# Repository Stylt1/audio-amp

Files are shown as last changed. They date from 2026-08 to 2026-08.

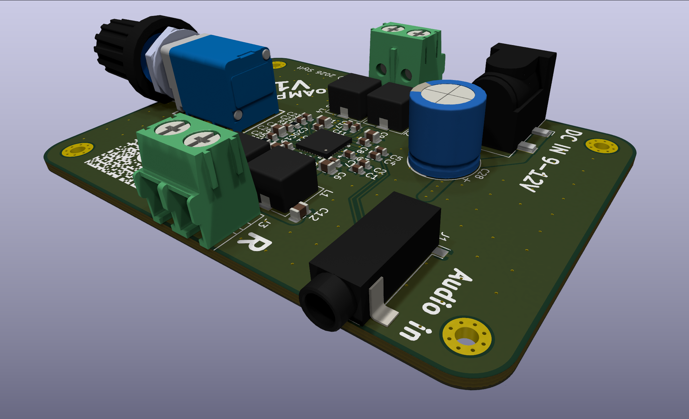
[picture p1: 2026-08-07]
img/Angle.backleft.png

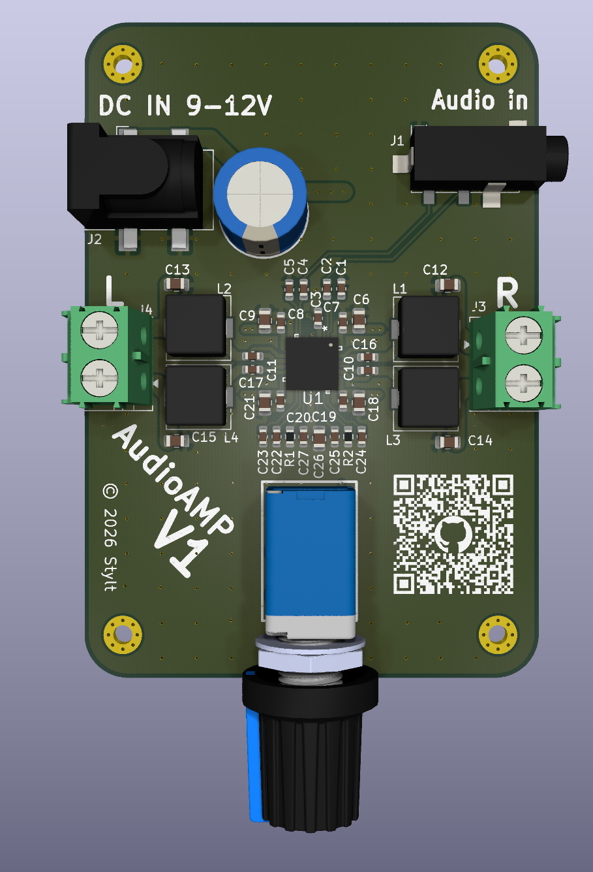
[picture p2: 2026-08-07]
img/Top.png

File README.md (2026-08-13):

View this project on [CADLAB.io](https://cadlab.io/project/30509). 

# 🎵 AudioAMP V1







This project features a 4-layer Class-D stereo audio amplifier based on **PAM8610** IC, delivering up to **2x 10W** output power.

---

## 📑 Table of Contents
- [✨ Key Features](#-key-features)
- [🛠️ Hardware Specifications](#️-hardware-specifications)
- [🧩 System Block Diagram](#-system-block-diagram)
- [📂 Repository Structure](#-repository-structure)
- [📸 Gallery & Schematics](#-gallery--schematics)

---

## ✨ Key Features

- **Amplification:** **PAM8610** (Class-D) stereo amplifier providing **2x 10W** output power.
- **4-Layer PCB Stackup:** 4-layer board design with dedicated power and ground planes:
  - **F.Cu (Top):** Signal + GND fill
  - **In1.Cu (Inner 1):** GND fill
  - **In2.Cu (Inner 2):** Power
  - **B.Cu (Bottom):** Secondary signal + GND fill
- **Supply Voltage Range:** from **9V to 12V DC** via standard DC05 DC Barrel Jack.
- **Volume & Power Control:** **10K logarithmic potentiometer** with an ON/OFF switch.
- **Connections:** 3.5 mm AUX stereo input jack and screw terminal blocks for Left (L) and Right (R) speakers.
- **Clean sound:** Bulk **2200 µF** electrolytic decoupling capacitor on power supply lines + LC output filters (33µH inductors) for ripple noise reduction and high signal fidelity.

---

## 🛠️ Hardware Specs

| Parameter | Specification |
| :--- | :--- |
| **Amplifier IC** | PAM8610 (Class-D Stereo) |
| **Output Power** | 10W + 10W RMS (into 8Ω @ 12V DC) |
| **Supply Voltage** | 9V – 12V DC |
| **PCB Stackup** | 4-Layer FR4 (Top, In1 [GND], In2 [PWR], Bottom) |
| **Power Connector** | 5.5 x 2.1 mm DC Barrel Jack |
| **Audio Input** | 3.5 mm Stereo AUX Jack |
| **Speaker Outputs** | Screw Terminal Blocks (Left & Right) |
| **Potentiometer** | 10K Logarithmic with ON/OFF Switch |
| **Filtration** | 2200 µF Bulk Electrolytic Cap + Output LC Filters |

---

## 🧩 System Block Diagram

<p align="center">
    BlockDiagram

</p>

---

## 📦 Production & Manufacturing Files

All production files required for manufacturing and PCBA assembly are located in the `production/` directory or under [GitHub Releases](../../releases):

---

## 📂 Repository Structure

```text
AudioAMP-V1/
├── hardware/              # KiCad project source files (.kicad_pro, .kicad_sch, .kicad_pcb)
├── img/                   # Documentation graphics, 3D renders, and layer views
├── production/            # Manufacturing deliverables
│   ├── bom/               # Bill of Materials (CSV)
│   ├── gerbers/           # 4-Layer Gerber files (ZIP archive)
│   └── schematics/        # Schematic diagram (PDF)
├── LICENSE.txt            # License
└── README.md              # Main project documentation
```

---

## 📸 Gallery & Schematics

### 3D Render
| Top View | Angled View |
|:---:|:---:|
| Top| Angle frontleft|

### 4-Layer PCB Layout

| Top Layer (F.Cu) | Inner Layer 1 (In1.Cu - GND) |
|:---:|:---:|
| F Cu| In1 Cu|

| Inner Layer 2 (In2.Cu - PWR) | Bottom Layer (B.Cu) |
|:---:|:---:|
| In2 Cu| B Cu|

### Schematic Diagram
Snímek obrazovky 2026-08-06 v 15 06 18

---

## 📝 License & Author

- **Designer:** Stylt
- **License:** ([CC BY-NC-ND 4.0 License](LICENSE))

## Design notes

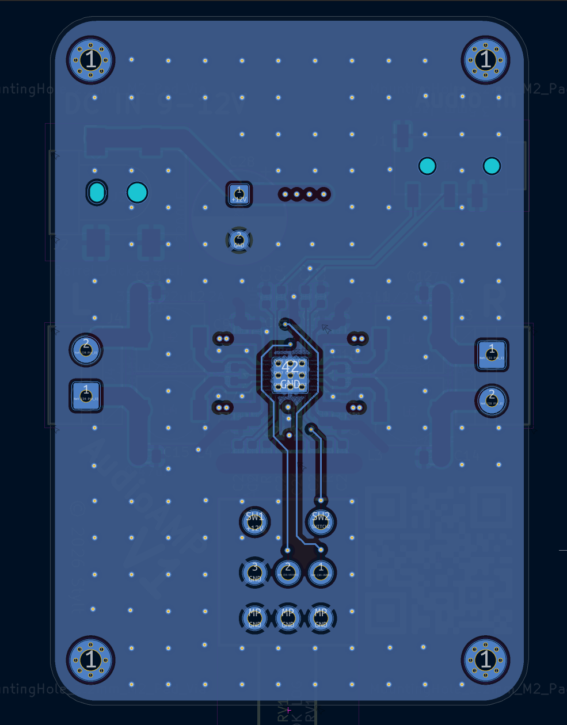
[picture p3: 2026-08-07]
img/B.Cu.png

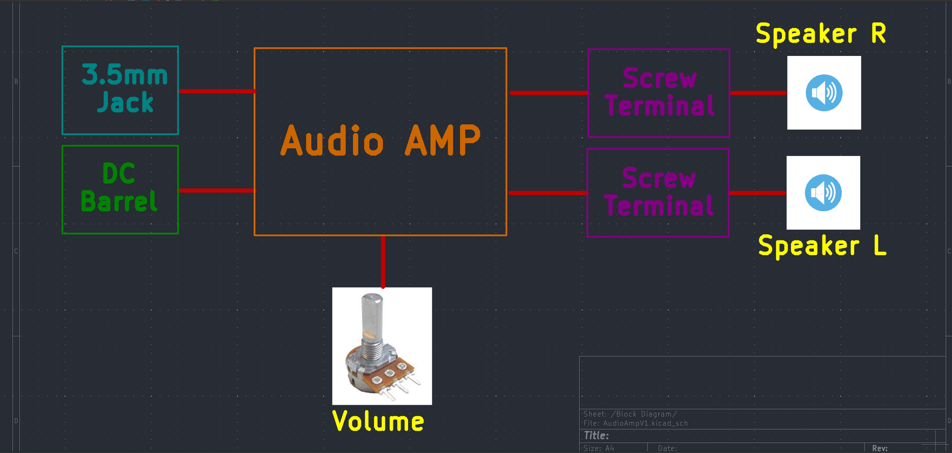
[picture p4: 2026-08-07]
img/BlockDiagram.png

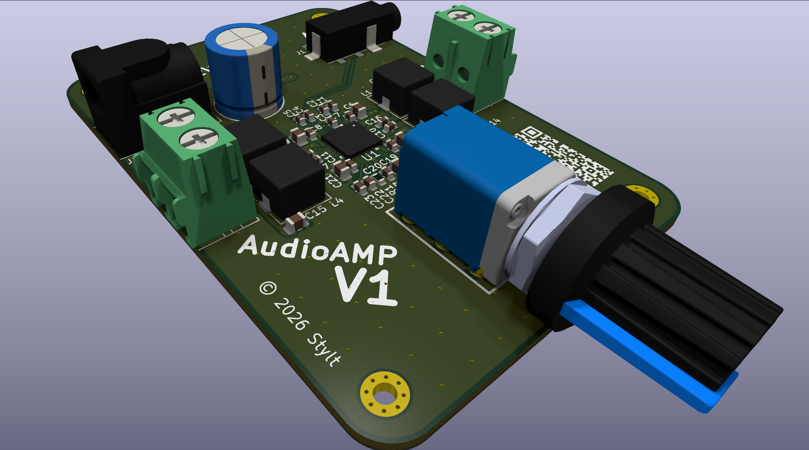
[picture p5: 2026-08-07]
img/Angle.frontleft.png

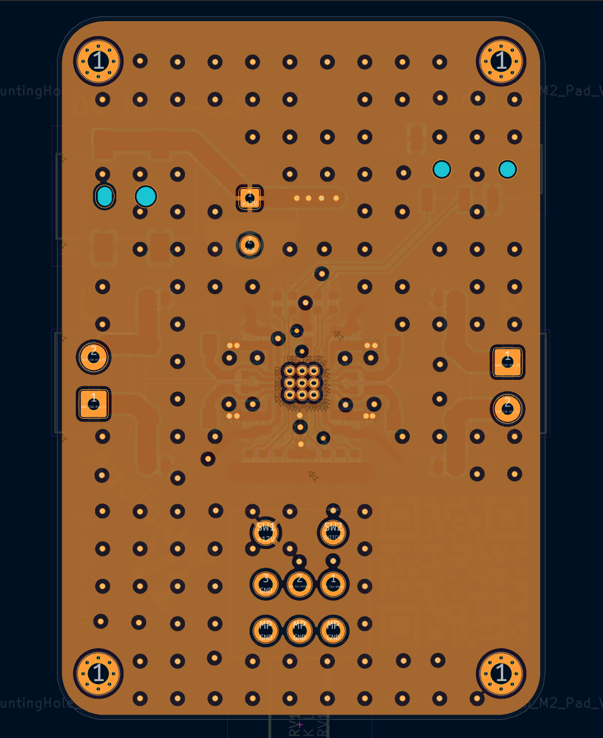
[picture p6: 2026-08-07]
img/In2.Cu.png

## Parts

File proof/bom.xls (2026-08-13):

Comment | Designator | Footprint | JLCPCB Part # | Qty | Ext.Price($)
100nF | C27 | 0603 | C14663 | 2 | 0.04
0,47uF | C12,C13,C14,C15 | 0805 | C16780 | 8 | 1.42
120K | R1 | 0603 | C25808 | 2 | 0.01
PAM8610 | U1 | QFN40-40P-POWER | C80797 | 2 | 2.74
1uF | C1,C10,C11,C16,C17,C19,C2,C20,C23,C24,C25,C3,C4,C5,C7,C8 | 0603 | C15849 | 32 | 2.42
220pF | C22 | 0603 | C1603 | 2 | 0.02
100K | R2 | 0603 | C25803 | 2 | 0.02
10uF | C18,C21,C26,C6,C9 | 0805 | C440198 | 10 | 3.22
2200uF | C28 | CP_Radial_D10.0mm_P5.00mm | C48970397 | 2 | 0.90
33uH/22uH,2A | L1,L2,L3,L4 | L_7.3x7.3_H4.5 | C207844 | 9 | 1.09
3,5mmJack | J1 | Jack_3.5mm_KoreanHropartsElec_PJ-320D-4A_Horizontal | C49563388 | 2 | 0.12
Barrel_Jack_Switch | J2 | BarrelJack_CLIFF_FC681465S_SMT_Horizontal | C52125089 | 2 | 0.64

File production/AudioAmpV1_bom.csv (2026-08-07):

Designator | Footprint | Quantity | Value | LCSC Part #
C1, C10, C11, C16, C17, C19, C2, C20, C23, C24, C25, C3, C4, C5, C7, C8 | 0603 | 16 | 1uF
C12, C13, C14, C15 | 0805 | 4 | 0,47uF
C18, C21, C26, C6, C9 | 0805 | 5 | 10uF
C22 | 0603 | 1 | 220pF
C27 | 0603 | 1 | 100nF
C28 | CP_Radial_D10.0mm_P5.00mm | 1 | 2200uF
J1 | Jack_3.5mm_KoreanHropartsElec_PJ-320D-4A_Horizontal | 1 | 3,5mm Jack
J2 | BarrelJack_CLIFF_FC681465S_SMT_Horizontal | 1 | Barrel_Jack_Switch
J3 | TerminalBlock_MaiXu_MX126-5.0-02P_1x02_P5.00mm | 1 | Speaker_R
J4 | TerminalBlock_MaiXu_MX126-5.0-02P_1x02_P5.00mm | 1 | Speaker_L
L1, L2, L3, L4 | L_7.3x7.3_H4.5 | 4 | 33uH/22uH, 2A
R1 | 0603 | 1 | 120K
R2 | 0603 | 1 | 100K
RV1 | AudioPot | 1 | 10K LOG
U1 | QFN40-40P-POWER | 1 | PAM8610

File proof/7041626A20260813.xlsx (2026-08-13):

?Designator | Value | Footprint | Quantity
J4 | Speaker_L | TerminalBlock_MaiXu_MX126-5.0-02P_1x02_P5.00mm | 1
J3 | Speaker_R | TerminalBlock_MaiXu_MX126-5.0-02P_1x02_P5.00mm | 1
RV1 | 10KLOG | AudioPot | 1

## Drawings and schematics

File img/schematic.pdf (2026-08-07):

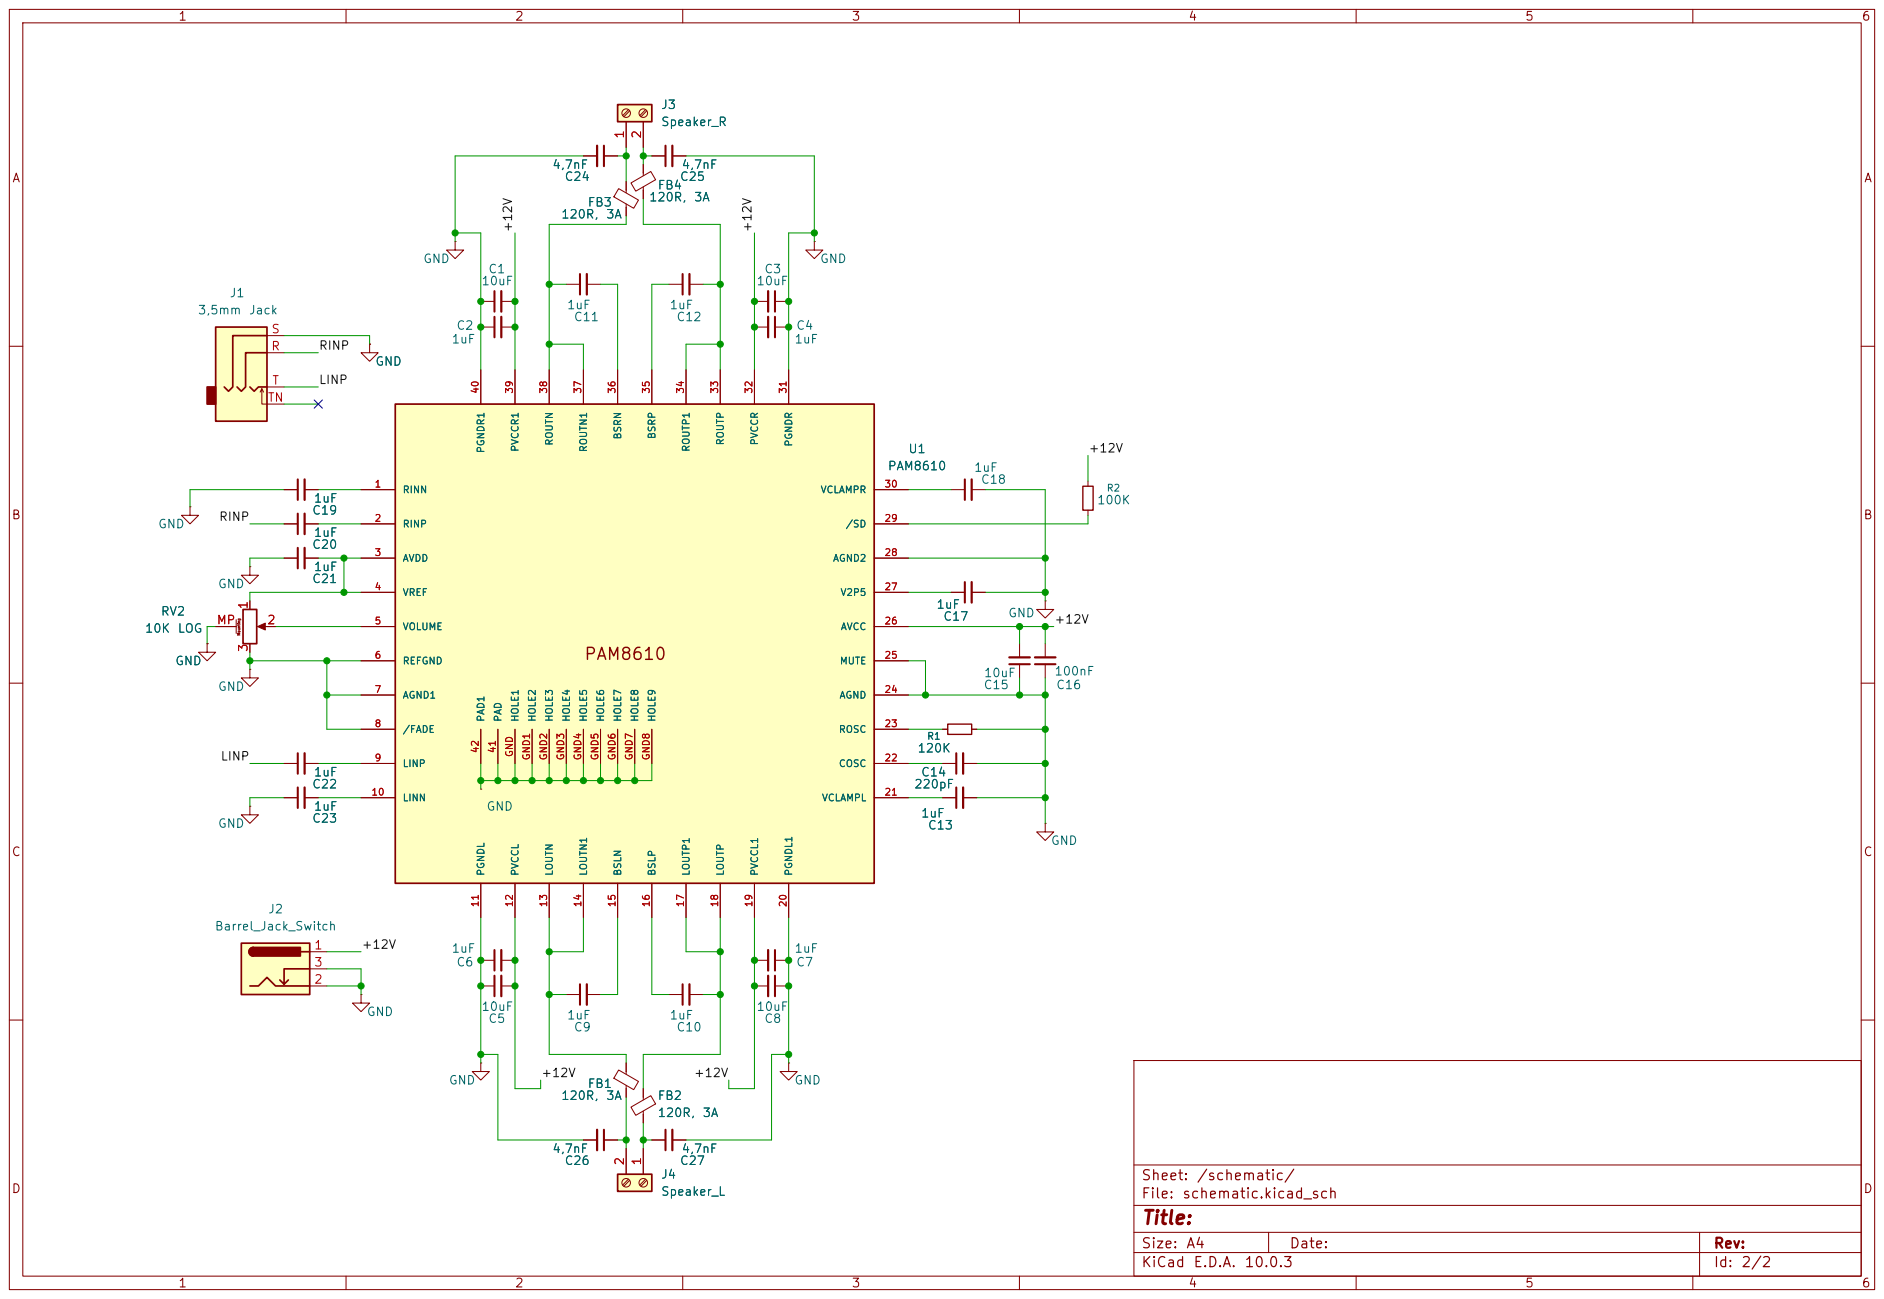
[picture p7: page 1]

RINN 1 RINP 2 | 1uF C18

AVDD 3

Size: A4 | Rev:
KiCad E.D.A. 10.0.3 | Id: 2/2

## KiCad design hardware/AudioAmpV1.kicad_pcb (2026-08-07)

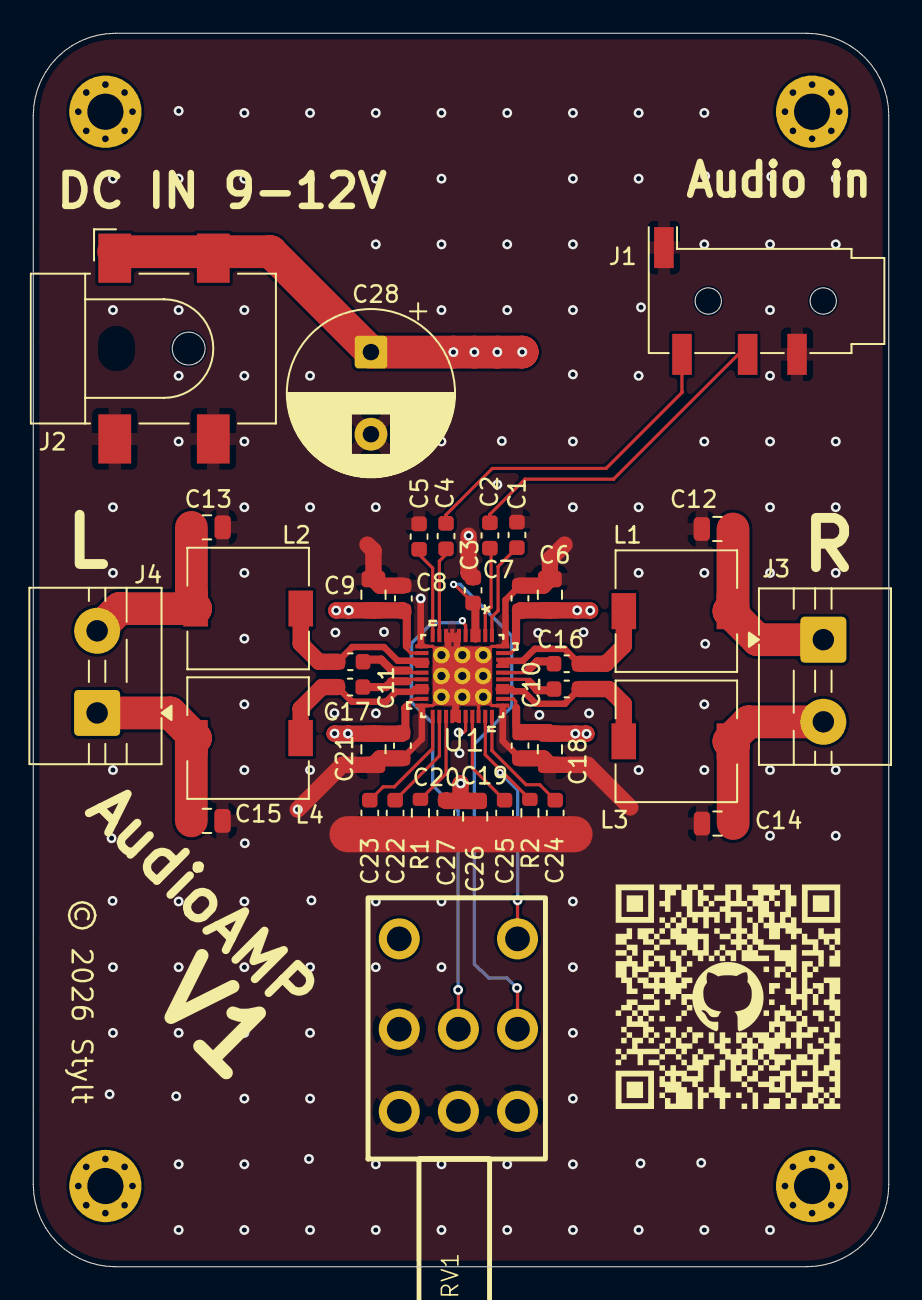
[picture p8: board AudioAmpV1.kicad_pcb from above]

Board: 4 copper layers, 52.1 x 75.1 mm, 40 parts (0 on the bottom side), 28 nets.

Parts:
C1, C2, C3, C4, C5, C7, C8, C10, C11, C16, C17, C19, C20, C23, C24, C25: 1uF; C_0603_1608Metric
C6, C9, C18, C21, C26: 10uF; C_0805_2012Metric
C12, C13, C14, C15: 0,47uF; C_0805_2012Metric
C22: 220pF; C_0603_1608Metric
C27: 100nF; C_0603_1608Metric
C28: 2200uF; CP_Radial_D10.0mm_P5.00mm
J1: 3,5mm Jack; Jack_3.5mm_KoreanHropartsElec_PJ-320D-4A_Horizontal
J2: Barrel_Jack_Switch; BarrelJack_CLIFF_FC681465S_SMT_Horizontal
J3: Speaker_R; TerminalBlock_MaiXu_MX126-5.0-02P_1x02_P5.00mm
J4: Speaker_L; TerminalBlock_MaiXu_MX126-5.0-02P_1x02_P5.00mm
L1, L2, L3, L4: 33uH/22uH, 2A; L_7.3x7.3_H4.5
R1: 120K; R_0603_1608Metric
R2: 100K; R_0603_1608Metric
RV1: 10K LOG; AudioPot
U1: PAM8610; QFN40-40P-POWER

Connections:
/schematic/+12V: C6.2, C7.2, C8.2, C9.2, C18.2, C19.2, C20.2, C21.2, C26.2, C27.2, C28.1, J2.1, RV1.SW1, U1.12 (PVCCL), U1.19 (PVCCL1), U1.26 (AVCC), U1.32 (PVCCR), U1.39 (PVCCR1)
/schematic/LINP: C4.1, J1.T
/schematic/RINP: C2.1, J1.R
/schematic/SWITCH2: R2.1, RV1.SW2, U1.29 (/SD)
GND: C1.1, C3.1, C5.1, C6.1, C7.1, C8.1, C9.1, C12.2, C13.2, C14.2, C15.2, C18.1, C19.1, C20.1, C21.1, C22.2, C23.2, C24.2, C25.2, C26.1, C27.1, C28.2, J1.S, J2.2, J2.3, R1.2, R2.2, RV1.3, RV1.MP (MountPin), U1.6 (REFGND), U1.7 (AGND1), U1.8 (/FADE), U1.11 (PGNDL), U1.20 (PGNDL1), U1.24 (AGND), U1.25 (MUTE), U1.28 (AGND2), U1.31 (PGNDR), U1.40 (PGNDR1), U1.41 (PAD), U1.42 (PAD1), U1.GND (HOLE1), U1.GND1 (HOLE2), U1.GND2 (HOLE3), U1.GND3 (HOLE4), U1.GND4 (HOLE5), U1.GND5 (HOLE6), U1.GND6 (HOLE7), U1.GND7 (HOLE8), U1.GND8 (HOLE9)
unnamed: C12.1, J3.1, L1.1
unnamed: C14.1, J3.2, L3.1
unnamed: C15.1, J4.1, L4.2
unnamed: C13.1, J4.2, L2.2
unnamed: C3.2, RV1.1, U1.3 (AVDD), U1.4 (VREF)
unnamed: C11.2, U1.15 (BSLN)
unnamed: C17.1, U1.16 (BSLP)
unnamed: C10.2, U1.36 (BSRN)
unnamed: C16.1, U1.35 (BSRP)
unnamed: C22.1, U1.22 (COSC)
unnamed: C5.2, U1.10 (LINN)
unnamed: C4.2, U1.9 (LINP)
unnamed: C11.1, L2.1, U1.13 (LOUTN), U1.14 (LOUTN1)
unnamed: C17.2, L4.1, U1.17 (LOUTP1), U1.18 (LOUTP)
unnamed: C1.2, U1.1 (RINN)
unnamed: C2.2, U1.2 (RINP)
unnamed: R1.1, U1.23 (ROSC)
unnamed: C10.1, L1.2, U1.37 (ROUTN1), U1.38 (ROUTN)
unnamed: C16.2, L3.2, U1.33 (ROUTP), U1.34 (ROUTP1)
unnamed: C25.1, U1.27 (V2P5)
unnamed: C23.1, U1.21 (VCLAMPL)
unnamed: C24.1, U1.30 (VCLAMPR)
unnamed: RV1.2, U1.5 (VOLUME)

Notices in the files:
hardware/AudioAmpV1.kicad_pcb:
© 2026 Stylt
